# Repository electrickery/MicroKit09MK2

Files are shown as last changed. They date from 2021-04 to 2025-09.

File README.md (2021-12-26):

## Description

In several 1983 editions of the French computer magazine 'Led' an MC6809 
single board computer was published, supporting a 6-digit, 7-segment Led 
display and 34 keys. The original has a 2 kByte monitor ROM and 2 kByte 
RAM. 

<p align="center"><a href="uK09_6809uP.jpg">
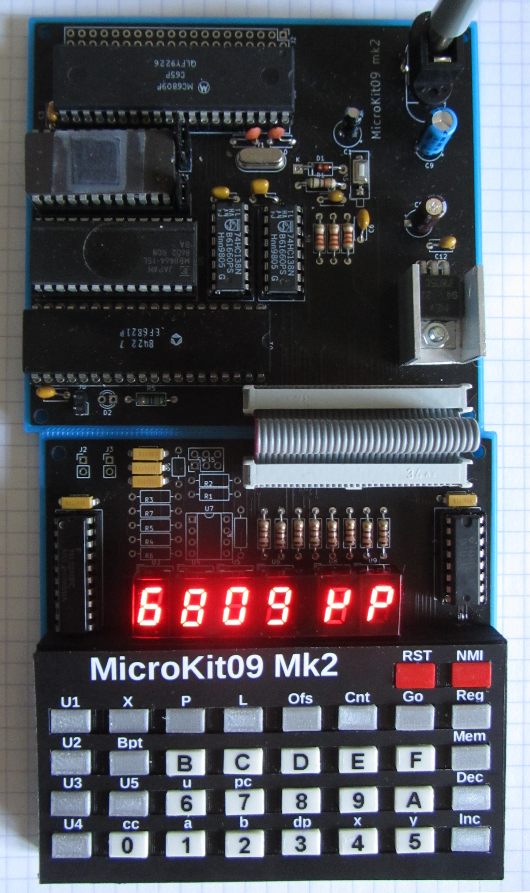
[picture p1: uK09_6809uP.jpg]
the two-part single board computer running a demo program.
</a>

Most published material can be found here: 
https://lab.nethence.com/frederic/Microit09/

This is a recreation, with a smaller footprint and some room for 
expansion.

The original, published monitor version is 1.8. This repository contains
my minor enhancements.

My webpage on the subject can be found here: 
http://electrickery.nl/comp/microKit09/

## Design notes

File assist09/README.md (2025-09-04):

## ASSIST09 on the MicroKit09MK2

ASSIST09 as configured in this directory requires RAM at $0000 to $1FFF, ROM at $E000-$FFFF and an ACIA (MC6850) at $A400-$A401. 

For the trace function, a PMT (MC6840) at $A800-$A807 is needed, with the output of Timer1 (pin 27) connected to the NMI input of the processor.

There is no custom schematic (yet), but it is a combination of the MicroKit09MK2-CPU board and the MicroKit09MK2 Serial/Timer board.

fjkraan@electrickery.nl, 2025-09-04

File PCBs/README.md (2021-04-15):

MicroKit09 and MicroKit09_OI are the CPU and I/O (display, keyboard & 
cassette interface) boards.

The main differences from the 1980's original are:
* the form factor, 
* inter-board connector, 
* display type,
* keyboard construction,
* expansion connector (most pins use the 6809 pinout),
* ROM-size jumper (2 kByte / 4 kByte),
* RAM size jumper (2 kByte / 8 kByte),
* controllable LED on CPU-board (connects to PIA-CB2, also cassette out),
* added more address decoding for the I/O segment at A000h, reducing the
  memory range of the PIA to 1 kByte (was 8 kByte). A chip-select signal
  for A400h-A7FFh is available on the expansion connector.

MicroKit09Serial is the (as yet) untested serial interface.

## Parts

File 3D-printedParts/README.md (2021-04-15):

These ate the 3D-printed parts I used for the MicroKit09 construction.
Not all are essential, but these two are:

* keyboardPanel8 - The keyboard switch cover

* keyTop3 - The key tops. 34 of these are needed

These are optional

* microKitKeyboardOverlayFrame2  - A frame to keep the keyboard overlay in place

* tapeFrame3 - A guide to help aligning the DymoTag characters.

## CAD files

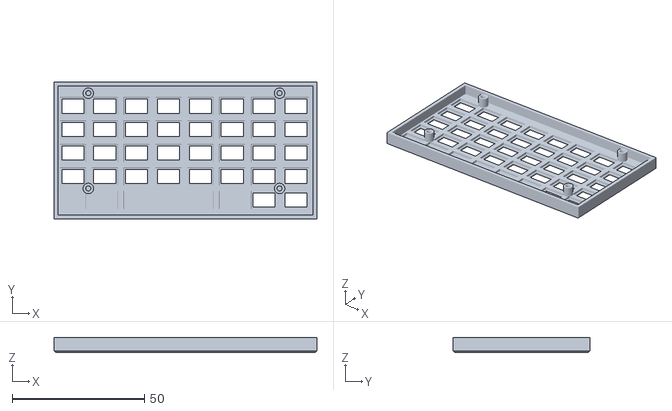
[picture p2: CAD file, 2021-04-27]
3D-printedParts/keyboardPanelLowProfile11.stl
99.6 x 51.8 x 5.50

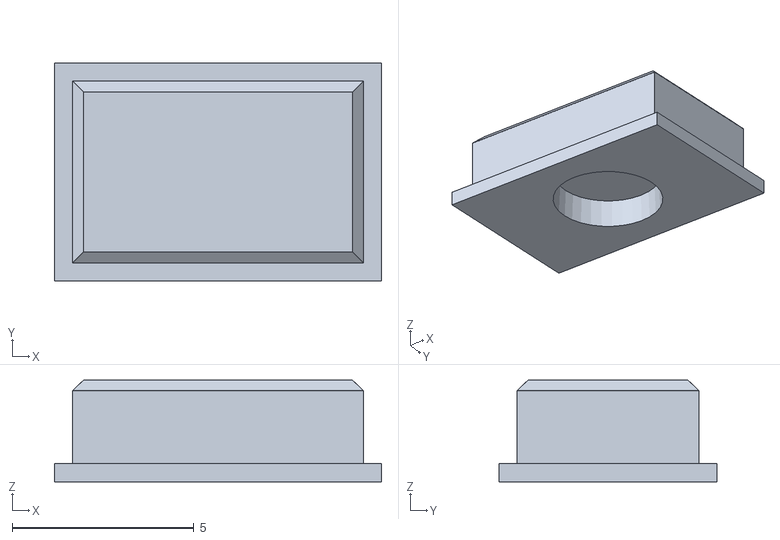
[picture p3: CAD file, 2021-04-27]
3D-printedParts/keyTopLowProfile4.stl
9.00 x 6.00 x 2.80

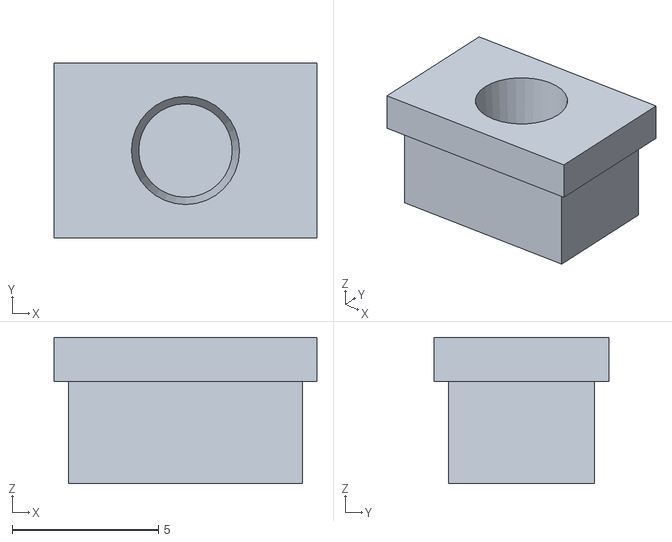
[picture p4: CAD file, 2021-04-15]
3D-printedParts/keyTop3.stl
9.00 x 6.00 x 5.00

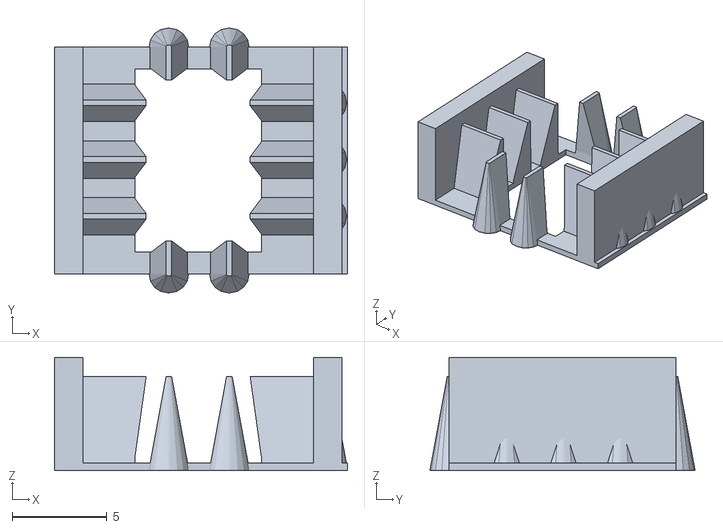
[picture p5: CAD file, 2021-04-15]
3D-printedParts/tapeFrame3.stl
15.5 x 14.0 x 6.00

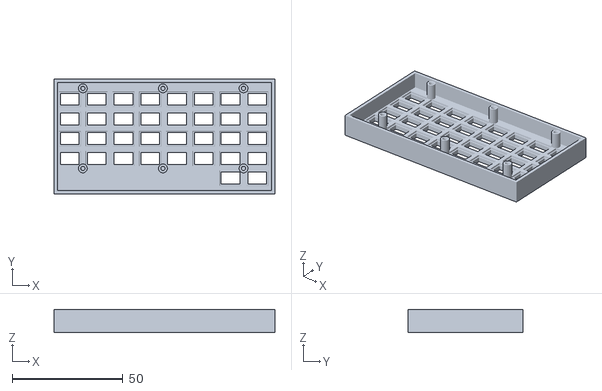
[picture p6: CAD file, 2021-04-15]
3D-printedParts/keyboardPanel8.stl
99.6 x 51.8 x 10.4

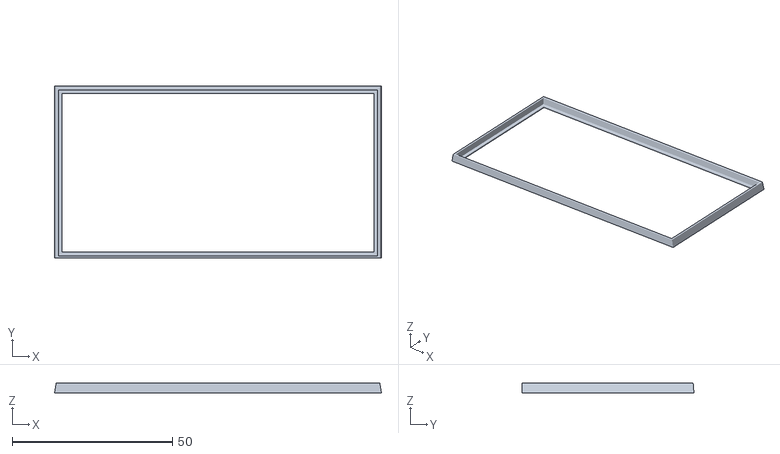
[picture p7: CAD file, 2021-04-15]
3D-printedParts/microKitKeyboardOverlayFrame2.stl
102.0 x 53.6 x 3.00

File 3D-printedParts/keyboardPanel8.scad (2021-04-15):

// keyboardPanel8

inch = 2.54;
$fn =  32;

keyDistX = 12.065; // 4.8 * inch;
keyDistY = 8.890; // 3.5 * inch;
//echo("keyDistX: ", keyDistX);
//echo("keyDistY: ", keyDistY);

//rowOffset = keyTopWidth / 2 + 2.5; // 4.191; // 
//columnOffset = keyTopHeight; // 7.684; // ;


keyTopWidth = 8.0 + 0.3;
keyTopHeight = 5.0 + 0.3;
keyTopThickness = 5.0;
keyTopHoleDepth = 4.0;
keyTopZoffset = keyTopThickness - keyTopHoleDepth;
keyTopRimZOffset = 3.5;
rimSize = 0.5 + 0.2;
keyHoleTaper = 1.05;
skirtWall = 1.5;

panelThick = 3.0;
panelWidth = 99.568; //keyDistX * 8 + keyTopWidth + 2.0;
panelHeight = keyDistY * 5 + keyTopHeight + 2.0;
echo("panelWidth: ", panelWidth); // 99.568
echo("panelHeight:", panelHeight);

standDiam = 4.0;
standHole = 1.9;
standHeight = 7.4;

module panelPcbStand() {
    taper = 0.7;
    taperHeight = standHeight -  taper;
    difference() {
        cylinder(d = standDiam, h = standHeight);
        translate([0, 0, -0.01]) cylinder(d = standHole, h = standHeight + 0.02);
        translate([0, 0, taperHeight]) cylinder(d1 = standHole, d2 = standHole + 0.5, h = taper + 0.01);
    }
}

module keyCutouts() {
    rowLength = 7;
    columnLength = 4;
    rowOffset = keyTopWidth / 2 - 1.15; // + 2.5
    columnOffset = keyTopHeight - 0.85; 
    for (x = [0.0: 1.0: rowLength]) {
        for (y = [0.0: 1.0: columnLength]) {
            translate([keyDistX * x + rowOffset, keyDistY * y + columnOffset, -0.01])
                key();
        }
    }
}

module key() {
    // key proper
    taperKeyHole(keyTopWidth, keyTopHeight, keyTopThickness, keyHoleTaper);
    // key rim
    translate([-rimSize, -rimSize, keyTopRimZOffset])
//         cube([keyTopWidth + rimSize * 2, 
//            keyTopHeight + rimSize * 2, 
//            keyTopThickness - keyTopRimZOffset]);
    taperKeyHole(keyTopWidth + rimSize * 2, 
            keyTopHeight + rimSize * 2, 
            keyTopThickness - keyTopRimZOffset,
            keyHoleTaper);
}

module panel() {
    difference() {
        cube([panelWidth, panelHeight, panelThick]);
        translate([0, 0, -1.3]) keyCutouts();
    }
    // mask most top row holes
    translate([0, 0, 0]) cube([73.0, 12.0, panelThick]);
}

//difference() {
    panel();
//    translate([3, 10, -0.01])
//        color("gray") 
//            microKitText();
//}
translate([0, 0, panelThick]) keyBoardSkirt();

startXOffset = 13.0;
startYOffset = 11.5;
distX1 = 36.068;
distX2 = 36.322;
distY = 36.068;

translate([0, 0, panelThick]) {
    
    translate([startXOffset, startYOffset, 0]) panelPcbStand();
    translate([startXOffset + distX1, startYOffset, 0]) panelPcbStand();
    translate([startXOffset + distX1 + distX2, startYOffset, 0]) panelPcbStand();
    translate([startXOffset, startYOffset + distY, 0]) panelPcbStand();
    translate([startXOffset + distX1, startYOffset + distY, 0]) panelPcbStand();
    translate([startXOffset + distX1 + distX2, startYOffset + distY, 0]) panelPcbStand();
}

module taperKeyHole(width, height, thickness, tapering) {
    translate([width / 2, height / 2, 0]) {
      linear_extrude(height = thickness, scale = tapering) 
        square([width, height], center = true);
    }
}

module keyBoardSkirt() {
  difference() {
    cube([panelWidth, panelHeight, standHeight]);
    translate([skirtWall, skirtWall, -0.01])
      cube([panelWidth - skirtWall * 2, panelHeight - skirtWall * 2, standHeight + 0.02]);
  }
}

module microKitText() {
    mirror([0,1,0])
    minkowski() {
        linear_extrude(height = 0.1) { 
            text("MicroKIT09 MK2", 6);}
        cylinder(d1=0.5, d2=0.01, h=1);
    }
}

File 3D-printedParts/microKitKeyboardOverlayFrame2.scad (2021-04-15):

// microKitKeyboardOverlayFrame2

keyDistX = 12.065; // 4.8 * inch;
keyDistY = 8.890; // 3.5 * inch;
keyTopHeight = 5.0 + 0.3;
panelThick = 3.0;
panelWidth = 99.568; //keyDistX * 8 + keyTopWidth + 2.0;
panelHeight = keyDistY * 5 + keyTopHeight + 2.0;

frameRim = 1.2;

frameTopHeight = 0.5;
frameWidth  = panelWidth + frameRim * 2;
frameHeight = panelHeight + frameRim * 2;
frameDepth = 3.0;

difference() {
    taperFrame(frameWidth, frameHeight, frameDepth, 0.99);
    translate([frameRim * 2, frameRim * 2, -0.01])
        cube([panelWidth - frameRim * 2, panelHeight - frameRim * 2, panelThick]);
    translate([frameRim, frameRim, frameTopHeight])
        cube([panelWidth, panelHeight, panelThick]);
    translate([0,0,-0.01]) cube([frameWidth, 0.5, frameDepth + 0.1]);
}

module taperFrame(width, height, thickness, tapering) {
    translate([width / 2, height / 2, 0]) {
      linear_extrude(height = thickness, scale = tapering) 
        square([width, height], center = true);
    }
}

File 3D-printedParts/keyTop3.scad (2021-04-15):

// keyTop3

keyTopWidth = 8.0;
keyTopHeight = 5.0;
keyTopThickness = 5.0;

keyTopHole1 = 3.2;
keyTopHole2 = 3.7;
keyTopHoleDepth = 4.0;
keyTopRimZOffset = 3.5;
rimSize = 0.5;

module keyTop() {
    keyTopZoffset = keyTopThickness - keyTopHoleDepth;
    difference() {
        union() {
            cube([keyTopWidth, keyTopHeight, keyTopThickness]);
            translate([-rimSize, -rimSize, keyTopRimZOffset])
                cube([keyTopWidth + rimSize * 2, 
                    keyTopHeight + rimSize * 2, keyTopThickness - keyTopRimZOffset]);
        }
        translate([keyTopWidth / 2, keyTopHeight / 2, keyTopZoffset+ 0.01])
            cylinder(d1 = keyTopHole1, d2 = keyTopHole2, h = keyTopHoleDepth, $fn = 32);
    }
}

keyTop();

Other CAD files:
3D-printedParts/keyboardPanelLowProfile11.scad
3D-printedParts/keyTopLowProfile4.scad
3D-printedParts/tapeFrame3.scad

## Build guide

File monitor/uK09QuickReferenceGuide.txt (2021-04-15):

Quick Reference Guide in progress.

At startup and reset, the '-.... ..' prompt is shown. In this mode only some keys can be used:
Mem, BPt, Reg, Cnt, L, P, Go.

White keys:
0/cc
1/a
2/b
3/dp
4/x
5/y
6/u
7/pc
8-9, A-F

Grey keys:
Bpt - Set Breakpoint. Enter break point address at the '.... bp' prompt. The monitor returns to the '-... ..'
      prompt. After a subsequent Go, the program will stop at the specified address and enter register check mode.
Cnt - Continue after SWI or breakpoint. When in register check mode, press Cnt twice to continue the program.
Dec - Decrement address
Inc - Increment address
Mem - Memory read / write. Enter the address at the '.... .n' prompt. The data is shown and can be overwritten.
      The Dec and Inc keys are used to navigate through memory.
Go  - Execute program. Enter the start address at the '.... .G' prompt.
L   - Read data from tape
Ofs - Allows calculation of automatic offsets in RAM. Enter the address at the '.... Ar' prompt and press Go.  
      The offset is shown at the '.... 0F' prompt.
P -   Write data to tape
      Enter start address at '.... .S' prompt and end address at '.... .F'. When complete 'F... ..' is shown.
Reg - Register read / write. Select register at the '.... r' prompt. No Inc/Dec here.
X   - Used in combination with Ofs key for the automatic offset calculation.

Red keys:
RST - Reset
NMI - Non maskable interrupt

On a software intterrupt (SWI) the returns to the monitor in register check mode (Inc/Dec can be used):
  '..## .C' is the CC register,
  '..## .A' is the A register,
  '..## .b' is the B register,
  '..## .d' is the DP register,
  '#### .H' is the X register,
  '#### .Y' is the Y register,
  '#### .U' is the user stack register,
  '#### .P' is the PC register,
  '#### .S' is the system stack register.

Useful addresses:

07FA - 07FF - DISBUF, display buffer. 00 is all segments off, 7F is all segments on.

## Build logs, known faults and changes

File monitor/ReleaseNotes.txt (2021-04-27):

1.8 - the original version
- this version is intended for a 2 kByte ROM, from E000h to E7FFh. The
  executed code is expected from E000h-E7FFh. Due to incomplete address
  decoding, the monitor is mirrored in the range E000h to FFFFh.
- the original source is only changed to make it assemble with the 
  asm6809 (https://www.6809.org.uk/asm6809) and produce identical binary 
  code.
  
1.9 - (2021-04-15)
- The code execution range is moved to F800h,
- The display routine is changed to allow usage of the decimal point,
- The display routine is changed to remove ghosting from the previous
  character segments.
- To make space for the extra code, some branches are changed from 16-
  bit to 8-bit. There are two spare bytes in the 2 kByte space.

1.9  (2021-04-27)
- Reverted the execution address range back to E000h, as it seems to break
  user programs. The twi changed to the display routine and the space
  operation remain.

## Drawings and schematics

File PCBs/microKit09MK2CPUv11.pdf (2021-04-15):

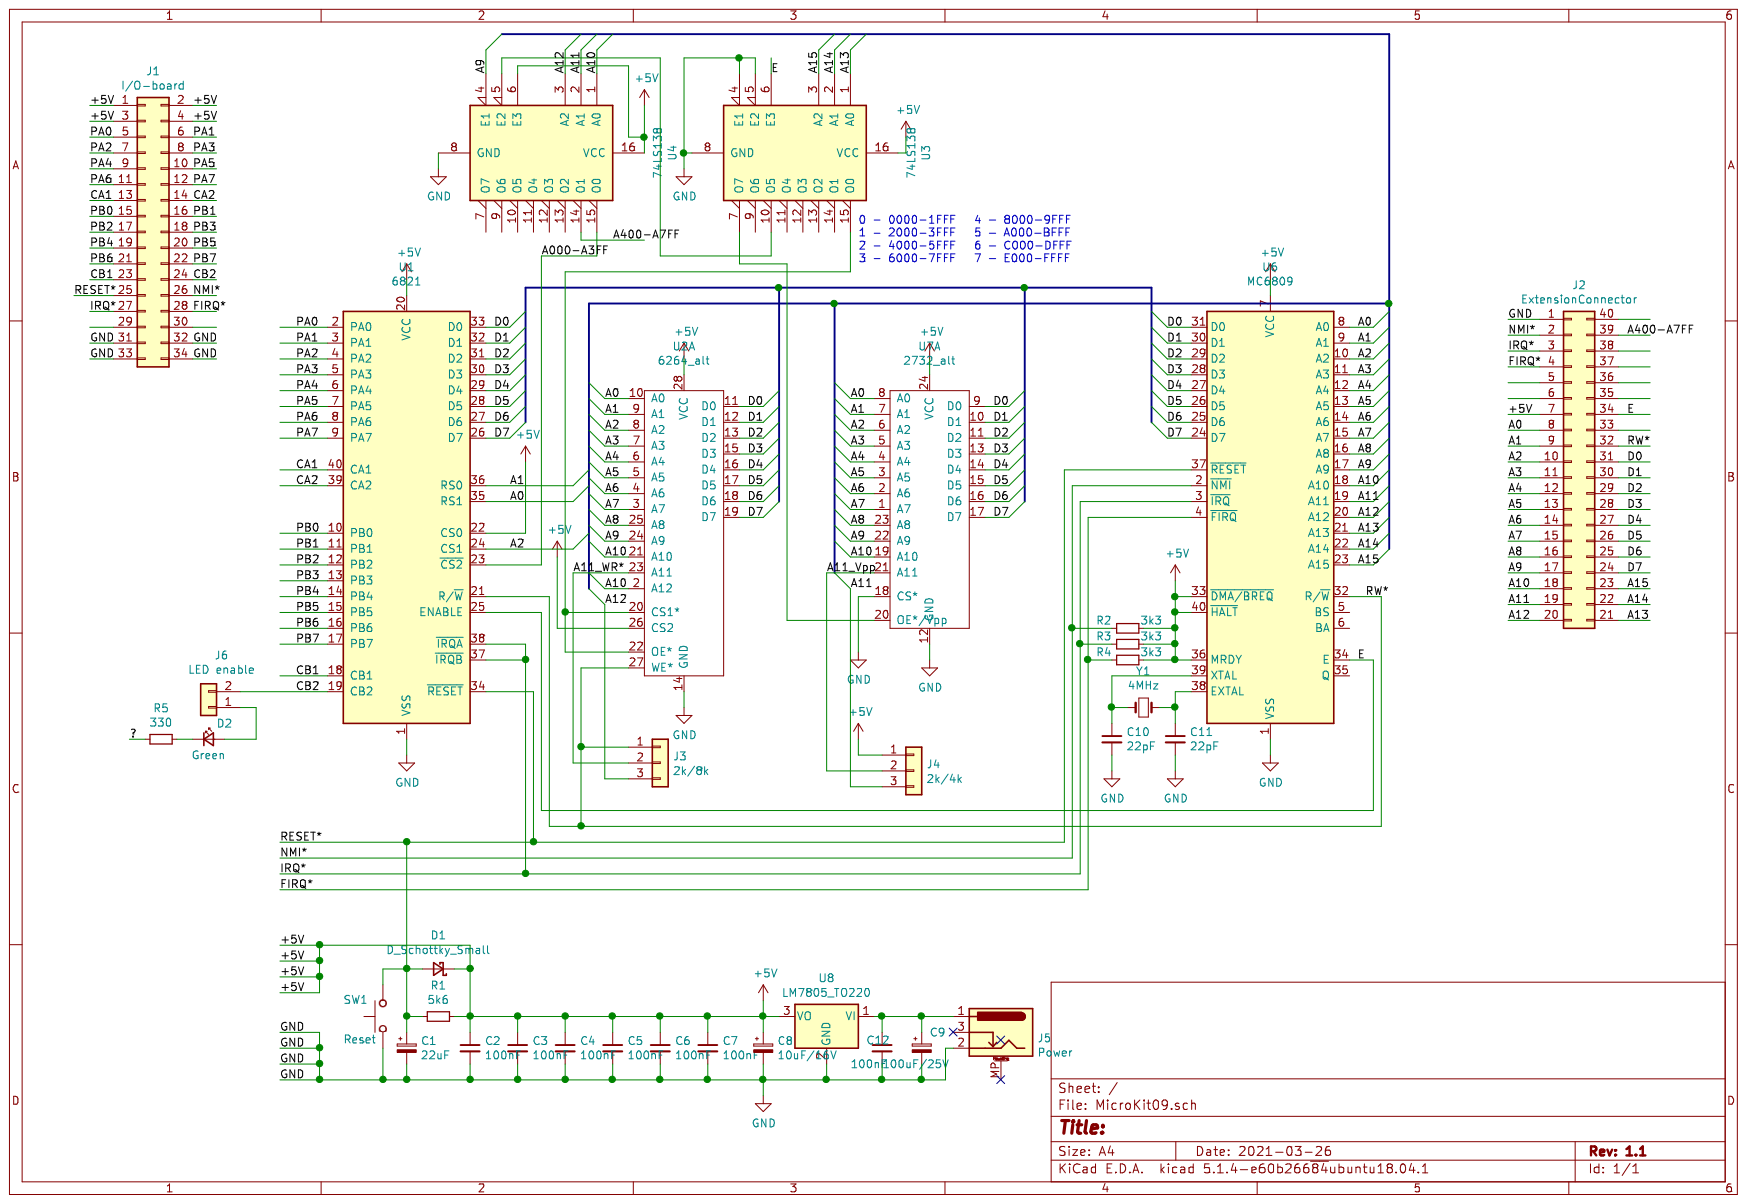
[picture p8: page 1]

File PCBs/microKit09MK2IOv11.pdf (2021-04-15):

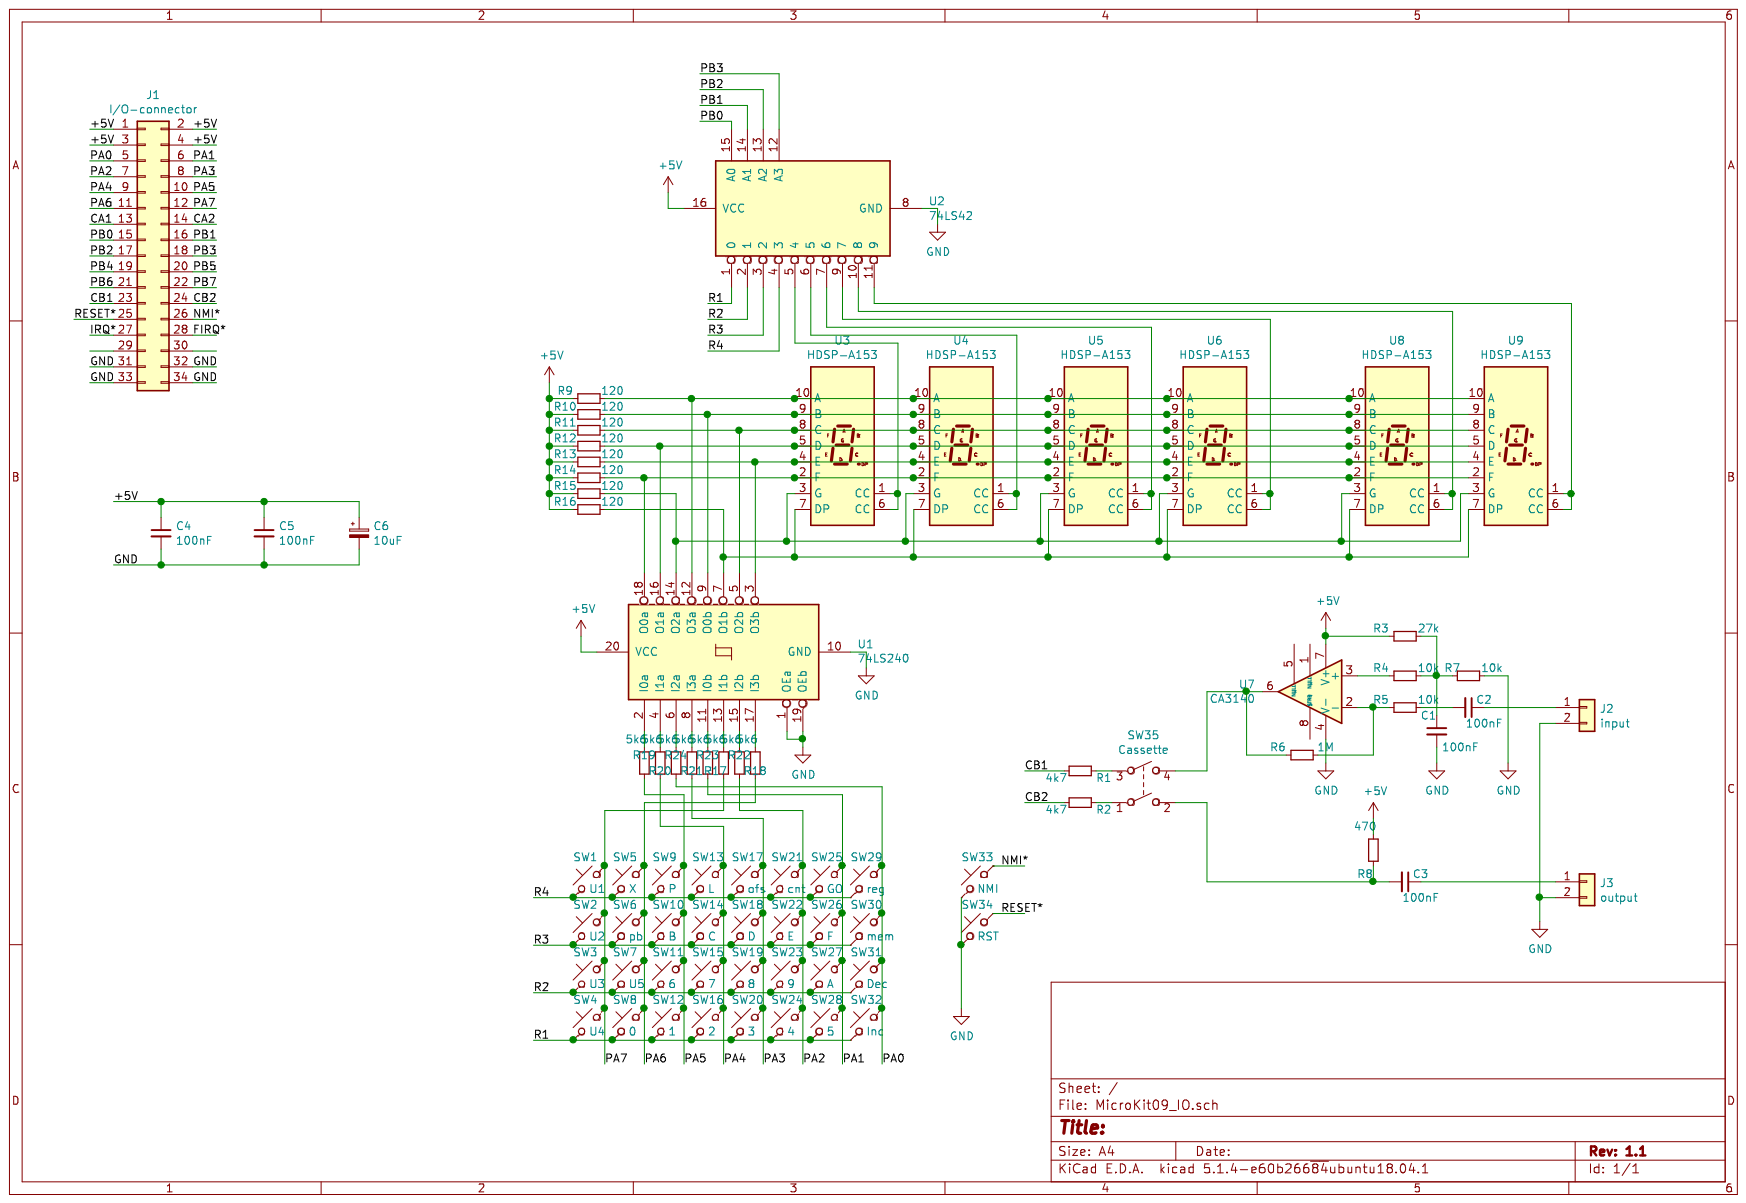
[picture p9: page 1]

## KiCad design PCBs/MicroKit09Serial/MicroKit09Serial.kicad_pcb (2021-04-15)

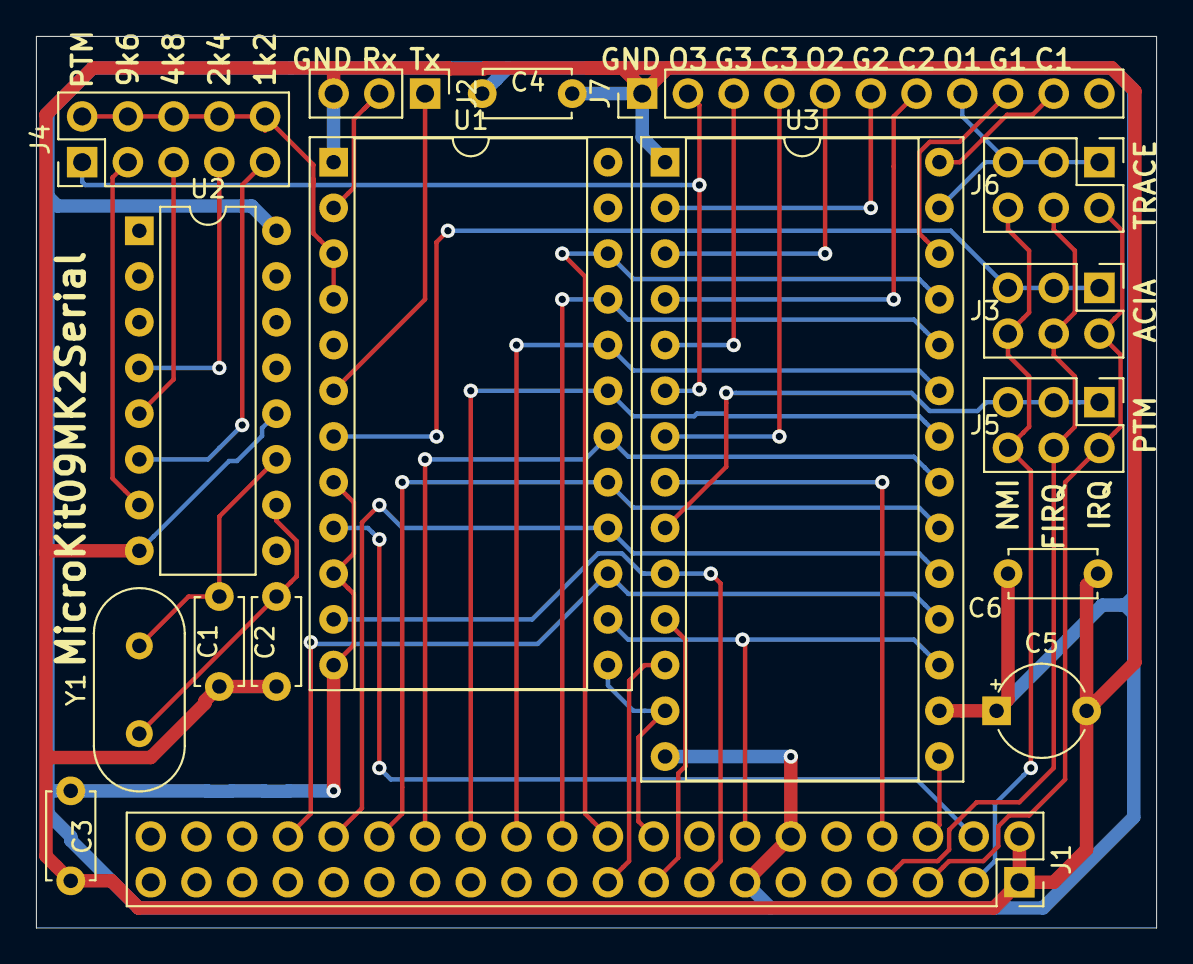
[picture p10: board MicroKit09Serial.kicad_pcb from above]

Board: 2 copper layers, 62.2 x 49.5 mm, 17 parts (0 on the bottom side), 41 nets.

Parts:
C1, C2: 22pF; C_Disc_D4.7mm_W2.5mm_P5.00mm
C3, C4, C6: 100nF; C_Disc_D4.7mm_W2.5mm_P5.00mm
C5: 100uF/16V; CP_Radial_Tantal_D5.0mm_P5.00mm
J1: ExpansionConnector; PinHeader_2x20_P2.54mm_Vertical_CW
J2: Serial; PinHeader_1x03_P2.54mm_Vertical
J3: ACIA_INT; PinHeader_2x03_P2.54mm_Vertical
J4: BaudrateSelect; PinHeader_2x05_P2.54mm_Vertical
J5: PTM_INT; PinHeader_2x03_P2.54mm_Vertical
J6: TRACE_INT; PinHeader_2x03_P2.54mm_Vertical
J7: PTM; PinHeader_1x11_P2.54mm_Vertical
U1: MC6850; DIP-24_W15.24mm_Socket
U2: 4060N; DIP-16_W7.62mm
U3: MC6840; DIP-28_W15.24mm_Socket
Y1: 2.4576MHz; Crystal_HC49-U_Vertical

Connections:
+5V: C3.1, C4.1, C5.1, C6.1, J1.7, J1.35, U1.8, U1.10, U1.12, U2.16, U3.14, U3.16
/1200Bd: J4.9, U2.6
/2400Bd: J4.7, U2.4
/4800Bd: J4.5, U2.5
/9600Bd: J4.3, U2.7
/A0: J1.8, U1.11, U3.10
/A1: J1.9, U3.11
/A2: J1.10, U3.12
/A400-A7FF*: J1.39, U1.9
/A800-ABFF*: J1.38, U3.15
/ACIA_IRQ*: J3.1, J3.3, J3.5, U1.7
/BaudRate: J4.2, J4.4, J4.6, J4.8, J4.10, U1.3, U1.4
/D0: J1.31, U1.22, U3.25
/D1: J1.30, U1.21, U3.24
/D2: J1.29, U1.20, U3.23
/D3: J1.28, U1.19, U3.22
/D4: J1.27, U1.18, U3.21
/D5: J1.26, U1.17, U3.20
/D6: J1.25, U1.16, U3.19
/D7: J1.24, U1.15, U3.18
/E: J1.34, U1.14, U3.17
/FIRQ*: J1.4, J3.4, J5.4, J6.4
/IRQ*: J1.3, J3.2, J5.2, J6.2
/NMI*: J1.2, J3.6, J5.6, J6.6
/PTM_C1*: J7.10, U3.28
/PTM_C2*: J7.7, U3.4
/PTM_C3*: J7.4, U3.7
/PTM_G1*: J7.9, U3.26
/PTM_G2*: J7.6, U3.2
/PTM_G3*: J7.3, U3.5
/PTM_IRQ*: J5.1, J5.3, J5.5, U3.9
/PTM_O1: J6.1, J6.3, J6.5, J7.8, U3.27
/PTM_O2: J7.5, U3.3
/PTM_O3: J4.1, J7.2, U3.6
/RESET*: J1.37, U3.8
/RW*: J1.32, U1.13, U3.13
GND: C1.2, C2.2, C3.2, C4.2, C5.2, C6.2, J1.1, J1.40, J2.3, J7.1, U1.1, U2.8, U2.12, U3.1
unnamed: C1.1, U2.11, Y1.2
unnamed: C2.1, U2.10, Y1.1
unnamed: J2.1, U1.6
unnamed: J2.2, U1.2

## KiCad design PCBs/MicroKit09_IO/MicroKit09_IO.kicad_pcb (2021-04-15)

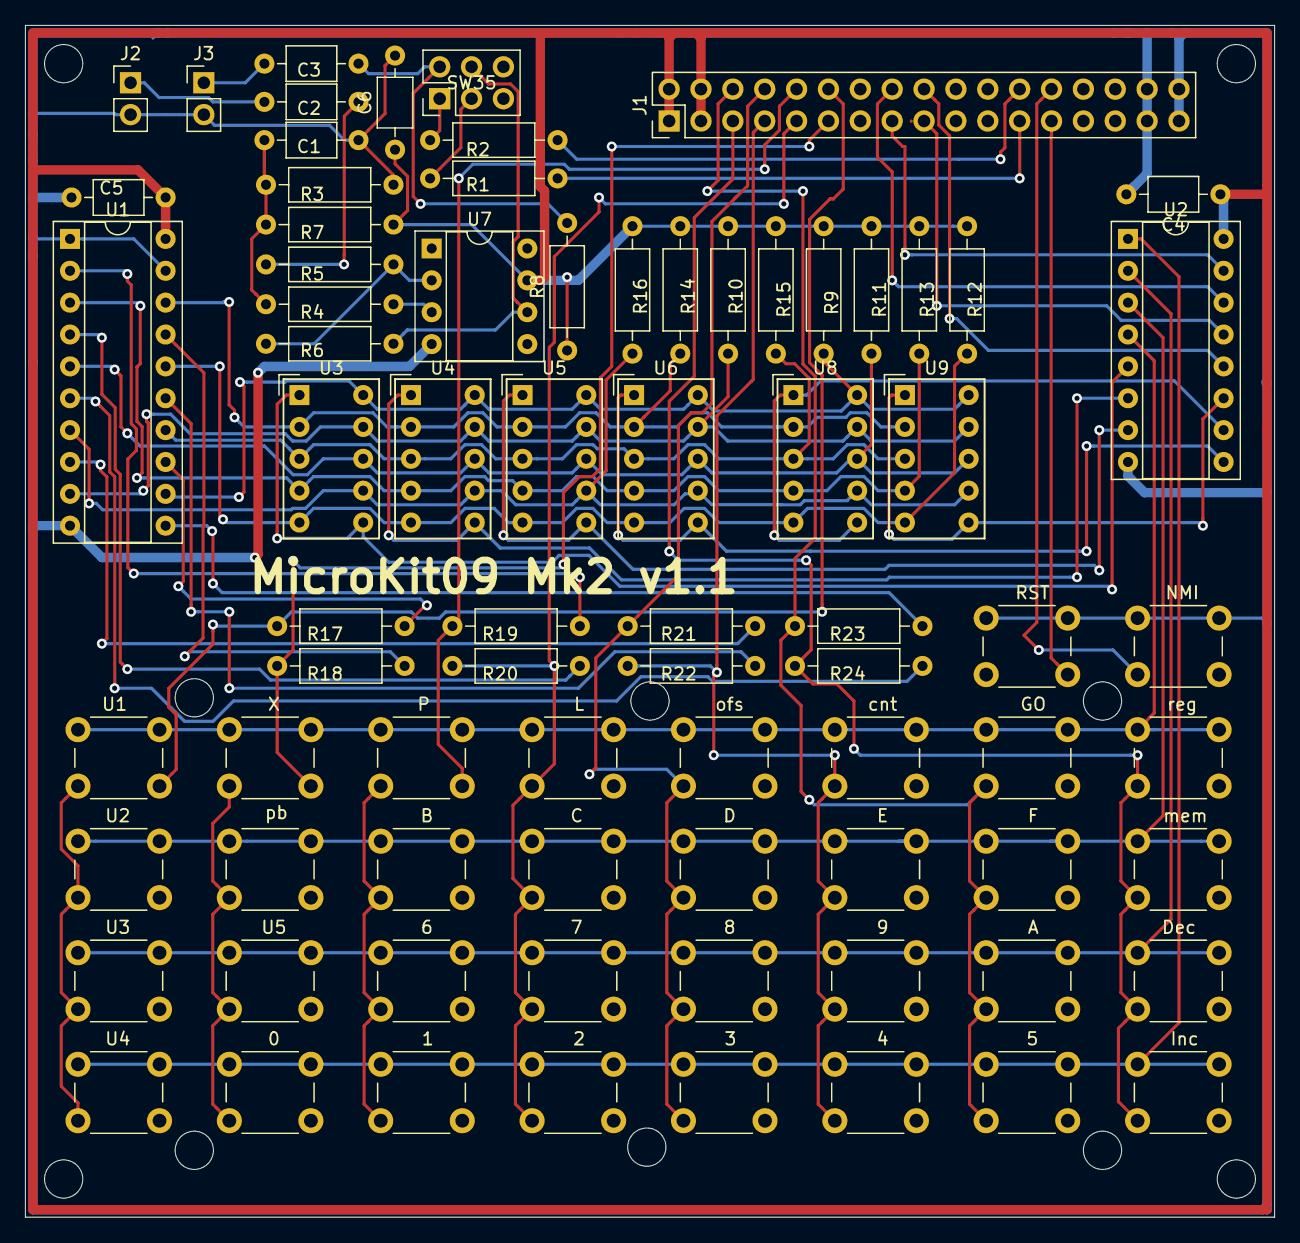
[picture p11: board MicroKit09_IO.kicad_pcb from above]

Board: 2 copper layers, 99.6 x 95.0 mm, 77 parts (0 on the bottom side), 54 nets.

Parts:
C1, C2, C3, C4, C5: 100nF; C_Axial_L3.8mm_D2.6mm_P7.50mm_Horizontal
C6: 10uF; C_Axial_L3.8mm_D2.6mm_P7.50mm_Horizontal
J1: I/O-connector; PinHeader_2x17_P2.54mm_Vertical
J2: input; PinHeader_1x02_P2.54mm_Vertical
J3: output; PinHeader_1x02_P2.54mm_Vertical
R1, R2: 4k7; R_Axial_DIN0207_L6.3mm_D2.5mm_P10.16mm_Horizontal
R3: 27k; R_Axial_DIN0207_L6.3mm_D2.5mm_P10.16mm_Horizontal
R4, R5, R7: 10k; R_Axial_DIN0207_L6.3mm_D2.5mm_P10.16mm_Horizontal
R6: 1M; R_Axial_DIN0207_L6.3mm_D2.5mm_P10.16mm_Horizontal
R8: 470; R_Axial_DIN0207_L6.3mm_D2.5mm_P10.16mm_Horizontal
R9, R10, R11, R12, R13, R14, R15, R16: 120; R_Axial_DIN0207_L6.3mm_D2.5mm_P10.16mm_Horizontal
R17, R18, R19, R20, R21, R22, R23, R24: 5k6; R_Axial_DIN0207_L6.3mm_D2.5mm_P10.16mm_Horizontal
SW1: U1; SW_PUSH_6mm_H5mm
SW2: U2; SW_PUSH_6mm_H5mm
SW3: U3; SW_PUSH_6mm_H5mm
SW4: U4; SW_PUSH_6mm_H5mm
SW5: X; SW_PUSH_6mm_H5mm
SW6: pb; SW_PUSH_6mm_H5mm
SW7: U5; SW_PUSH_6mm_H5mm
SW8: 0; SW_PUSH_6mm_H5mm
SW9: P; SW_PUSH_6mm_H5mm
SW10: B; SW_PUSH_6mm_H5mm
SW11: 6; SW_PUSH_6mm_H5mm
SW12: 1; SW_PUSH_6mm_H5mm
SW13: L; SW_PUSH_6mm_H5mm
SW14: C; SW_PUSH_6mm_H5mm
SW15: 7; SW_PUSH_6mm_H5mm
SW16: 2; SW_PUSH_6mm_H5mm
SW17: ofs; SW_PUSH_6mm_H5mm
SW18: D; SW_PUSH_6mm_H5mm
SW19: 8; SW_PUSH_6mm_H5mm
SW20: 3; SW_PUSH_6mm_H5mm
SW21: cnt; SW_PUSH_6mm_H5mm
SW22: E; SW_PUSH_6mm_H5mm
SW23: 9; SW_PUSH_6mm_H5mm
SW24: 4; SW_PUSH_6mm_H5mm
SW25: GO; SW_PUSH_6mm_H5mm
SW26: F; SW_PUSH_6mm_H5mm
SW27: A; SW_PUSH_6mm_H5mm
SW28: 5; SW_PUSH_6mm_H5mm
SW29: reg; SW_PUSH_6mm_H5mm
SW30: mem; SW_PUSH_6mm_H5mm
SW31: Dec; SW_PUSH_6mm_H5mm
SW32: Inc; SW_PUSH_6mm_H5mm
SW33: NMI; SW_PUSH_6mm_H5mm
SW34: RST; SW_PUSH_6mm_H5mm
SW35: Cassette; PinHeader_2x03_P2.54mm_Vertical
U1: 74LS240; DIP-20_W7.62mm_Socket
U2: 74LS42; DIP-16_W7.62mm_Socket
U3, U4, U5, U6, U8, U9: HDSP-A153; HDSP-A151
U7: CA3140; DIP-8_W7.62mm_Socket

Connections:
+5V: C4.1, C5.1, C6.1, J1.1, J1.2, J1.3, J1.4, R3.2, R8.1, R9.2, R10.2, R11.2, R12.2, R13.2, R14.2, R15.2, R16.2, U1.20, U2.16, U7.7
/CB1: J1.23, R1.1
/CB2: J1.24, R2.1
/NMI*: J1.26, SW33.2
/PA0: J1.5, R24.2, SW29.2, SW30.2, SW31.2, SW32.2
/PA1: J1.6, R23.2, SW25.2, SW26.2, SW27.2, SW28.2
/PA2: J1.7, R22.2, SW21.2, SW22.2, SW23.2, SW24.2
/PA3: J1.8, R21.2, SW17.2, SW18.2, SW19.2, SW20.2
/PA4: J1.9, R20.2, SW13.2, SW14.2, SW15.2, SW16.2
/PA5: J1.10, R19.2, SW9.2, SW10.2, SW11.2, SW12.2
/PA6: J1.11, R18.2, SW5.2, SW6.2, SW7.2, SW8.2
/PA7: J1.12, R17.2, SW1.2, SW2.2, SW3.2, SW4.2
/PB0: J1.15, U2.15
/PB1: J1.16, U2.14
/PB2: J1.17, U2.13
/PB3: J1.18, U2.12
/R1: SW4.1, SW8.1, SW12.1, SW16.1, SW20.1, SW24.1, SW28.1, SW32.1, U2.1
/R2: SW3.1, SW7.1, SW11.1, SW15.1, SW19.1, SW23.1, SW27.1, SW31.1, U2.2
/R3: SW2.1, SW6.1, SW10.1, SW14.1, SW18.1, SW22.1, SW26.1, SW30.1, U2.3
/R4: SW1.1, SW5.1, SW9.1, SW13.1, SW17.1, SW21.1, SW25.1, SW29.1, U2.4
/RESET*: J1.25, SW34.2
GND: C1.2, C4.2, C5.2, C6.2, J1.31, J1.32, J1.33, J1.34, J2.2, J3.2, R7.1, SW33.1, SW34.1, U1.1, U1.10, U1.19, U2.8, U7.4
unnamed: C1.1, R3.1, R4.1, R7.2
unnamed: C2.1, J2.1
unnamed: C2.2, R5.1
unnamed: C3.1, J3.1
unnamed: C3.2, R8.2, SW35.2
unnamed: R1.2, SW35.3
unnamed: R2.2, SW35.1
unnamed: R4.2, U7.3
unnamed: R5.2, R6.1, U7.2
unnamed: R6.2, SW35.4, U7.6
unnamed: R9.1, U1.12, U3.10, U4.10, U5.10, U6.10, U8.10, U9.10
unnamed: R10.1, U1.9, U3.9, U4.9, U5.9, U6.9, U8.9, U9.9
unnamed: R11.1, U1.5, U3.8, U4.8, U5.8, U6.8, U8.8, U9.8
unnamed: R12.1, U1.16, U3.5, U4.5, U5.5, U6.5, U8.5, U9.5
unnamed: R13.1, U1.3, U3.4, U4.4, U5.4, U6.4, U8.4, U9.4
unnamed: R14.1, U1.18, U3.2, U4.2, U5.2, U6.2, U8.2, U9.2
unnamed: R15.1, U1.14, U3.3, U4.3, U5.3, U6.3, U8.3, U9.3
unnamed: R16.1, U1.7, U3.7, U4.7, U5.7, U6.7, U8.7, U9.7
unnamed: R17.1, U1.13
unnamed: R18.1, U1.17
unnamed: R19.1, U1.2
unnamed: R20.1, U1.4
unnamed: R21.1, U1.8
unnamed: R22.1, U1.15
unnamed: R23.1, U1.11
unnamed: R24.1, U1.6
unnamed: U2.5, U3.1, U3.6
unnamed: U2.6, U4.1, U4.6
unnamed: U2.7, U5.1, U5.6
unnamed: U2.9, U6.1, U6.6
unnamed: U2.10, U8.1, U8.6
unnamed: U2.11, U9.1, U9.6

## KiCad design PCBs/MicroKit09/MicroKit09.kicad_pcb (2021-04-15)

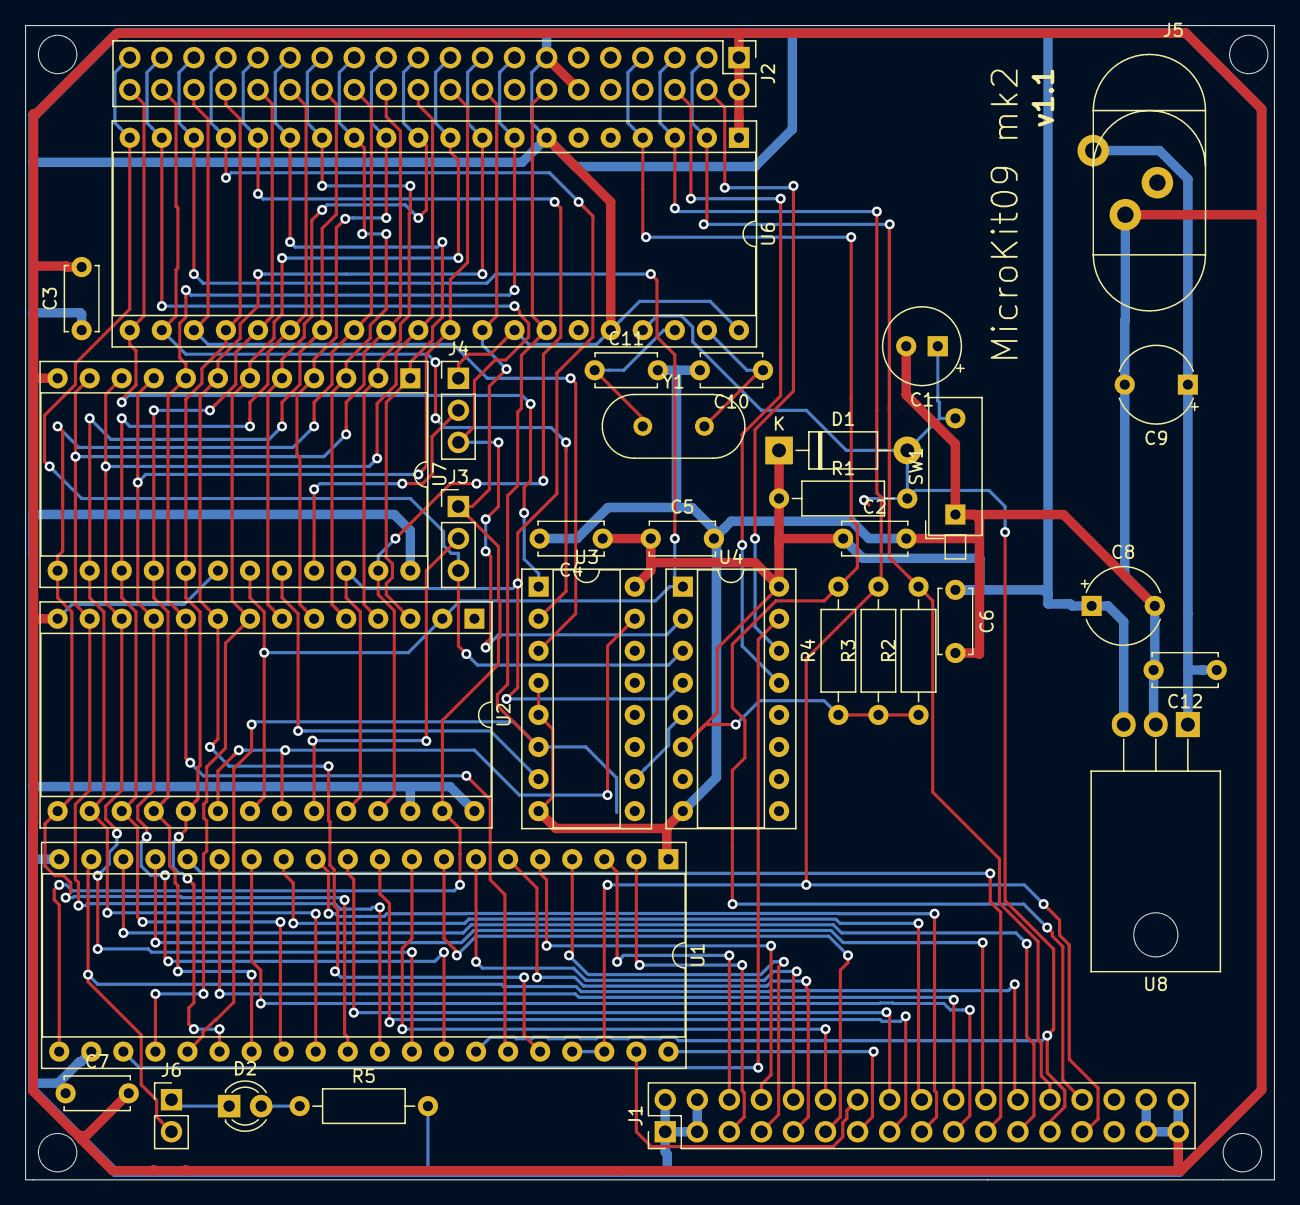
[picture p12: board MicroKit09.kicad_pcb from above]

Board: 2 copper layers, 98.9 x 91.4 mm, 34 parts (0 on the bottom side), 65 nets.

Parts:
C1: 22uF; CP_Radial_Tantal_D6.0mm_P2.50mm
C2, C3, C4, C5, C6, C7, C12: 100nF; C_Disc_D5.0mm_W2.5mm_P5.00mm
C8: 10uF/16V; CP_Radial_Tantal_D6.0mm_P5.00mm
C9: 100uF/25V; CP_Radial_Tantal_D6.0mm_P5.00mm
C10, C11: 22pF; C_Disc_D4.7mm_W2.5mm_P5.00mm
D1: D_Schottky_Small; D_DO-41_SOD81_P10.16mm_Horizontal
D2: Green; LED_D3.0mm
J1: I/O-board; PinHeader_2x17_P2.54mm_Vertical
J2: ExtensionConnector; PinHeader_2x20_P2.54mm_Vertical_CC
J3: 2k/8k; PinHeader_1x03_P2.54mm_Vertical
J4: 2k/4k; PinHeader_1x03_P2.54mm_Vertical
J5: Power; Barrel_Jack_vertical_alt
J6: LED enable; PinHeader_1x02_P2.54mm_Vertical
R1: 5k6; R_Axial_DIN0207_L6.3mm_D2.5mm_P10.16mm_Horizontal
R2, R3, R4: 3k3; R_Axial_DIN0207_L6.3mm_D2.5mm_P10.16mm_Horizontal
R5: 330; R_Axial_DIN0207_L6.3mm_D2.5mm_P10.16mm_Horizontal
SW1: Reset; SW_DIP_SPSTx01_Piano_10.8x4.1mm_W7.62mm_P2.54mm
U1: 6821; DIP-40_W15.24mm_Socket
U2: 6264_alt; DIP-28_W15.24mm_Socket
U3, U4: 74LS138; DIP-16_W7.62mm_Socket
U6: MC6809; DIP-40_W15.24mm_Socket
U7: 2732_alt; DIP-24_W15.24mm_Socket
U8: LM7805_TO220; TO-220-3_Horizontal_TabDown
Y1: 4MHz; Crystal_HC49-U_Vertical

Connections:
+5V: C2.1, C3.1, C4.1, C5.1, C6.1, C7.1, C8.1, D1.1, J1.1, J1.2, J1.3, J1.4, J2.7, J2.35, J4.1, R1.1, R2.1, R3.1, R4.1, R5.2, U1.20, U1.22, U2.26, U2.28, U3.16, U4.6, U4.16, U6.7, U6.33, U6.36, U6.40, U7.24, U8.3
/A0: J2.8, U1.35, U2.10, U6.8, U7.8
/A000-A3FF: U1.23, U4.15
/A1: J2.9, U1.36, U2.9, U6.9, U7.7
/A2: J2.10, U1.24, U2.8, U6.10, U7.6
/A3: J2.11, U2.7, U6.11, U7.5
/A4: J2.12, U2.6, U6.12, U7.4
/A5: J2.13, U2.5, U6.13, U7.3
/A6: J2.14, U2.4, U6.14, U7.2
/A7: J2.15, U2.3, U6.15, U7.1
/A8: J2.16, U2.25, U6.16, U7.23
/A9: J2.17, U2.24, U4.4, U6.17, U7.22
/A10: J2.18, U2.2, U2.21, U4.1, U6.18, U7.19
/A11: J2.19, J4.3, U4.2, U6.19
/A11_Vpp: J4.2, U7.21
/A11_WR*: J3.2, U2.23
/A12: J2.20, J3.3, U4.3, U6.20
/A13: J2.21, U3.1, U6.21
/A14: J2.22, U3.2, U6.22
/A15: J2.23, U3.3, U6.23
/A400-A7FF*: J2.39, U4.14
/A800-ABFF*: J2.38, U4.13
/CA1: J1.13, U1.40
/CA2: J1.14, U1.39
/CB1: J1.23, U1.18
/CB2: J1.24, J6.2, U1.19
/D0: J2.31, U1.33, U2.11, U6.31, U7.9
/D1: J2.30, U1.32, U2.12, U6.30, U7.10
/D2: J2.29, U1.31, U2.13, U6.29, U7.11
/D3: J2.28, U1.30, U2.15, U6.28, U7.13
/D4: J2.27, U1.29, U2.16, U6.27, U7.14
/D5: J2.26, U1.28, U2.17, U6.26, U7.15
/D6: J2.25, U1.27, U2.18, U6.25, U7.16
/D7: J2.24, U1.26, U2.19, U6.24, U7.17
/E: J2.34, U1.25, U3.6, U6.34
/FIRQ*: J1.28, J2.4, R4.2, U6.4
/IRQ*: J1.27, J2.3, R3.2, U1.37, U1.38, U6.3
/NMI*: J1.26, J2.2, R2.2, U6.2
/PA0: J1.5, U1.2
/PA1: J1.6, U1.3
/PA2: J1.7, U1.4
/PA3: J1.8, U1.5
/PA4: J1.9, U1.6
/PA5: J1.10, U1.7
/PA6: J1.11, U1.8
/PA7: J1.12, U1.9
/PB0: J1.15, U1.10
/PB1: J1.16, U1.11
/PB2: J1.17, U1.12
/PB3: J1.18, U1.13
/PB4: J1.19, U1.14
/PB5: J1.20, U1.15
/PB6: J1.21, U1.16
/PB7: J1.22, U1.17
/RESET*: C1.1, D1.2, J1.25, R1.2, SW1.2, U1.34, U6.37
/RW*: J2.32, J3.1, U1.21, U2.27, U6.32
GND: C1.2, C2.2, C3.2, C4.2, C5.2, C6.2, C7.2, C8.2, C9.2, C10.2, C11.2, C12.2, J1.31, J1.32, J1.33, J1.34, J2.1, J2.40, J5.2, SW1.1, U1.1, U2.14, U3.4, U3.5, U3.8, U4.8, U6.1, U7.12, U7.18, U8.2
unnamed: C10.1, U6.39, Y1.2
unnamed: C11.1, U6.38, Y1.1
unnamed: C9.1, C12.1, J5.1, U8.1
unnamed: D2.1, J6.1
unnamed: D2.2, R5.1
unnamed: U2.20, U2.22, U3.15
unnamed: U3.7, U7.20
unnamed: U3.10, U4.5

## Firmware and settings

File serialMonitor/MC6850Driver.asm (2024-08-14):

* Derived from the Sbug receive and transmit routines.
* fjkraan@electrickery.nl, 2024-08-09

* MC6850 registers
* Control Register (0. Wr)
* CR1 CR0 
*  0   0   /1
*  0   1   /16
*  1   0   /64
*  1   1   Master Reset

* CR4 CR3 CR2
*  1   0   1  8 Bits, 1 stop bit

* CR6 CR5
*  0   0   RTS = low, interrupt disabled
*  0   1   RTS = low, interrupt enabled
*  1   0   RTS = high, interrupt disabled
*  1   1   RTS = low, send BREAK, interrupt disabled

* CR7
*  0  Receive interrupt disable
*  1  Receive interrupt enable


* CPORT (0, Rd)
* Status register bits (valid when 1)
* SR0 - Receive data register full
* SR1 - Transmit data register empty
* SR2 - Data Carrier detect
* SR3 - Clear to Send
* SR4 - Framing Error
* SR5 - Receiver overrun
* SR6 - Parity Error
* SR7 - Interrupt Request

UARTC   EQU $A400
UARTS   EQU UARTC
UARTD   EQU UARTC+1

*               CR 7 65 432 10
*               0b 0 10 101 01 
UARTINI EQU     0b01010101 ;* /16, 8n1, no interrupt


; From SBUG source    
; Output Character from A; original name OUTCH
OUTCH	PSHS	A,X     ; push X first, then A
        LDX		CPORT   ; Load serial port base address
_OUTCW	LDA		,X      ; Load serial port status byte
        BITA	#2      ; Check Tx register
        BEQ		_OUTCW  ; Loop when not empty
        PULS	A       ; Get char back
        STA		1,X     ; Send char
        PULS	X       ; 
        RTS

; Input Character (wait for it, blocking) ; original name 
INCHW   PSHS   X          ; SAVE IX
        LDX     CPORT      ; POINT TO TERMINAL PORT
_INCW   LDA    ,X         ; FETCH PORT STATUS
        BITA    #1 TEST    ; READY BIT, RDRF ?
        BEQ     _INCW     ; IF NOT RDY, THEN TRY AGAIN
        LDA     1,X        ; FETCH CHAR
        PULS    X          ; RESTORE IX
        RTS

; Check Rx buffer
CHKRX   PSHS    X          ; SAVE IX
        LDX     CPORT      ; POINT TO TERMINAL PORT
        LDA     ,X         ; FETCH PORT STATUS
        BITA    #1 TEST    ; READY BIT, RDRF ?
        RTS

; Get Rx character in A and set or Z flag cleared if no char
INCHC   BSR     CHKRX
        BEQ     _ICNOCH
        LDA     UARTD
        RTS
_ICNOCH
RTS

;Push Order last to first!
;    Condition Code Register 
;    Accumulator A 
;    Accumulator B 
;    Direct Page Register 
;    Index Register X (HI)  
;    Index Register X (LO) 
;    Index Register Y (HI) 
;    Index Register Y (LO) 
;    User Stack Pointer/Hardware Stack Pointer (HI) 
;    User Stack Pointer/Hardware Stack Pointer (LO) 
;    Program Counter (HI) 
;    Program Counter (LO)

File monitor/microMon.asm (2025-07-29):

    NAM MICROMON09
* REV 1.10
*
*PROGRAMME MONITEUR POUR MC 6809
*
*ASSEMBLE SUR EUROMAK LE 20 JUILLET 1982


*****************************************
*PROGRAMME REALISE PAR CLAUDE VICIDOMINI*
*****************************************
*SAISI LE 21 JANVIER 2013 PAR F LE DUIGOU
*FIN DE VERIFICATION LE 26 JANVIER 2013
*Reformatted for explicit comments and assembly on April 28th, 2021 by F.J. Kraan
*with asm6809 (https://www.6809.org.uk/asm6809) to identical binary
*again for the Flex assembler format a09 (https://github.com/electrickery/A09)


*DEFINITION DES FONCTIONS:
***P - PUNCH CHARGE UNE ZONE MEMOIRE EN CASSETTE
***L - LOAD CHARGE LE CONTENU D'UNE CASSETTE EN MEMOIRE
***M - MEMORY EXAMINE ET CHANGE LE CONTENU D'UNE MEMOIRE
***AB- ABORT MET SOUS CONTROLE MONITEUR SANS INITIALISATION
***R - REGISTER DISPLAY
*      ORDRE DE VISUALISATION des REGISTRES:CC,A,B,DP,X,Y,U,PC,SP
*      LE CONTENU DES REGISTRES PEUT ETRE CHANGE A LA DEMANDE
***I - INCREMENT
*      INCREMENTE D'UN PAS LORS D'UNE FONCTION MEMOIRE
*      VISUALISE UN REGISTRE APRES L'AUTRE LORS D'UNE INTERRUPTION.
*      STOCKE EN MEMOIRE LA DONNEE RENTREE
***G - GO DEMARRE UN PROGRAMME APRES AVOIR PRECISE SON ADRESSE
*      PERMET D'EFFECTUER UN CALCUL D'OFFSET POUR UN ADRESSAGE
*      INDEXE OU POUR UN BRANCHEMENT RELATIF
***CN- CONTINUE PERMET DE CONTINUER LE DEROULEMENT D'UN PROGRAMME
*      APRES UN "ABORT".
***DN- DECREMENTATION: PERMET DE DECREMENTER D'UN PAS LORS D'UNE
*      FONCTION MEMOIRE OU DE VISUALISER LES REGISTRES DANS L'AUTRE
*      SENS.
***OF- OFFSET: CALCULE L'OFFSET LONG OU COURT LORS D'UNE
*      FONCTION MEMOIRE ET LE PLACE AUTOMATIQUEMENT DANS LA
*      MEMOIRE DE PROGRAMME, PUIS RETOURNE DANS LA FONCTION
*      MEMOIRE.
*X-OF- POST OCTET: PERMET DE CALCULER L'OFFSET EN DECIMAL QU'IL FAUT
*      DONNER AU POST OCTET; LE PROGRAMME LE CALCULE EN HEXA ET LE
*      PLACE EN MEMOIRE.
***BP- BREAKPOINT: INSERE UN SWI2 A UNE ADRESSE SPECIFIEE, VISUALISE
*      LE CONTENU DES REGISTRES DU MPU, PUIS PLACE L'INSTRUCTION EN MEM
*      A LA PLACE DU SWI2
*
*
*
*
********************************************************************
**LA PILE EST LOCALISEE A1 PARTIR DE L'ADRESSE $0780 "JUSQU'A $07CC"
**LA RAM PART DE L'ADRESSE $0000 JUSQU'A $07AF
**LE MONITEUR EST LOCALISE ENTRE $E000 ET $E7FF
**LE PIA EST LOCALISE ENTRE $A004 ET $A007
******************************************************************** 
********************************************************************
*  LE RESET EST SITUE A L'ADRESSE $E219.
*  LA ROUTINE DE NMI EST A L'ADRESSE $E27C.
*  LE SWI EST A L'ADRESSE $E2A7.
*  LE SWI2 EST A L'ADRESSE $E27C.
*  LES AUTRES INTERRUPS SONT DEFINIES DS "EMPLACEMENT DES REGISTRES"
********************************************************************
        ORG $E000
*
* SCRUTATION DU CLAVIER *
*
*              0   1   2   3
KEYTBL  FCB $06,$05,$04,$03
*
*              4   5   6   7
        FCB $02,$01,$15,$14
* 
*              8   9   A   B
        FCB $13,$12,$11,$25
*
*              C   D   E   F
        FCB $24,$23,$22,$21

* CODAGE DES SEGMENTS *
*
*              0   1   2   3
DIGTBL  FCB $7E,$06,$5B,$1F
*
*              4   5   6   7
        FCB $27,$3D,$7D,$0E
*
*              8   9   A   B
        FCB $7F,$3F,$6F,$75
*
*              C   D   E   F
        FCB $78,$57,$79,$69


**************  GETKEY ROUTINE  **************
*SCRUTE LES LIGNES ET LES COLONNES DU CLAVIER*
************ ALLUME LES AFFICHEURS ***********

GETKEY  PSHS Y,DP,B
        SETDP $A0
        LDA #$A0
        TFR A,DP
FINCLA  BSR DISPRE      ; ALLUMER LES AFFICHEURS
        CLRA            ; 
        STA <SCNREG     ; PIA Control Register A 2=0: DDR
        STA <SCNCNT     ; ACCES A DDRB  PIA DDR B
        STA <DISREG     ; PA EN ENTREE
        LDA #$0F        ; lower nibble output, upper nibble input
        STA <DISCNT     ; PB EN SORTIE  
        LDA #$04
        STA <SCNREG     ; ACCES A ORA-DISREG
        STA <SCNCNT     ; ACCES A DRB-DISCNT
        LDB #$FF
LIGSUI  INCB
        CMPB #$04       ; FIN SCRUT. CLAVIER?
        BEQ FINCLA      ; OUI, SCRUTER AFFICHEURS
        STB <DISCNT     ; NON, SCRUTER LIGNE PAR LIGNE
        LDA <DISREG
        COMA            ; PAS DE TOUCHE ENFONCEES?
        BEQ LIGSUI      ; OUI, SCRUTER LIGNE SUIV;
        STB SAVCNT     
        STA SAVREG      ; NON, TOUCHE ENFONCEE
        CLRA
        LDB #$01
COLSUI  CMPB SAVREG     ; TOUCHE DETECTEE?
        BEQ DECKEY      ; OUI, RECONNAITRE LA TOUCHE
        INCA            ; NON, PASSER A LA COLONNE SUIVANTE
        ASLB            ; TOUTES COLONNES TESTEES?
        BEQ LIGSUI      ; OUI, LIGNE SUIVANTE
        BRA COLSUI      ; NON,COLONNE SUIVANTE


************ RECONNAISSANCE DE LA TOUCHE ***********
*FABRIQUE LE CODE DE RECONNAISSANCE DE LA TOUCHE SI*
** ELLE EST APPUYEE     ; SUPPRIME LES REBONDISSEMENTS**

DECKEY  LDB SAVCNT      ; NUMERO DE LIGNE
        ASLB
        ASLB
        ASLB
        ASLB
        PSHS B          ; REPERE LIGNE
        ADDA ,S+
        PSHS A          ; SAUVEGARDE CODE TOUCHE
        LDY #$0008
NOREB   CLRB
DLY2    LDA <DISREG
        COMA            ; REBONDISSEMENT ?
        BNE NOREB       ; OUI, ATTENDRE DISPARITION
        DECB            ; NON, TEMPO=30MS
        BNE DLY2
        LEAY -1,Y
        BNE DLY2
        PULS PC,Y,DP,B,A    ; RETOUR RESET ROUTINE ; RTS


****** ALLUMAGE DES AFFICHEURS ******


DISPRE  PSHS X,B,A
        LDX #DISREG
        CLRA
        STA 2,X             ; ACCES A DDRA
        STA 3,X             ; ACCES A DDRB
        LDA #$FF            ; Set all port lines to output, decimal point too
        STA ,X              ; PA EN SORTIE
        LDA #$0F
        STA 1,X             ; PB0-3 EN SORTIE
        LDA #$04
        STA 2,X             ; ACCES A PA-DISREG
        STA 3,X             ; ACCES A PB-DISCNT
        LDX #DISBUF
        LDB #$03
RECOM   INCB
        CMPB #$0A           ; TOUS LES AFFICHEURS SCRUTES?
        BNE SCRUTA          ; NON, CONTINUER
        PULS PC,X,B,A       ; OUI, RETOUR SOUS GETKEY ; RTS


****** ALLUMER UN AFFICHEUR APRES L'AUTRE *******


SCRUTA  STB >DISCNT         ; CHOISIR L'AFFICHEUR
        LDA ,X+             ; PRENDRE CARACTERE DS DISBUF
        ORA MABS            ; Set the dp-segment for absent memory
        COMA
        STA DISREG          ; ALLUMER SEGMENTS
        LDA #$A0
DLY1    DECA
        BNE DLY1            ; DUREE #1MS
    
    
        LDA #$FF            ; Clear all segments
        STA DISREG          ;  before next display
    
    
        BRA RECOM           ; ALLUMER TOUS LES AFFICHEURS

*** CHARGEMENT DE L'ADRESSE DANS X ***


FADDRX  EXG A,B
        TFR D,X             ; D=X=ADRESSE PROGRAMME
        PULS PC,B,A         ; RTS


****** FABRICATION DES ADRESSES ******
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

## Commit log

2021-04-15 Initial monitor version and corrected PCBs and 3D-printed parts.
    [MicroKit09.kicad_pcb, MicroKit09.sch, MicroKit09Serial.kicad_pcb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]
2021-04-15 Documentation updates.
    [keyTopParsepartout1.scad, keyTopParsepartout1.stl]
2021-04-27 Added low-profile keyboard parts.
    [keyTopLowProfile4.scad, keyTopLowProfile4.stl, keyboardPanelLowProfile11.scad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]
2021-04-27 Reverted ORG location to E000h.
    [microMon.asm]
2025-07-19 Assembler format switch, minor additions. Almost working "memory-present" indicator.
2025-07-29 Added 6309 check to banner, fixed key test routine.
    [microMon.asm]
2025-09-03 ASSIST09 source code added compatible with the MicroKit09MK2 serial/timer extension.
